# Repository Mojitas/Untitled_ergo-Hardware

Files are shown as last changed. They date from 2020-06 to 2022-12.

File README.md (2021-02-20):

# untitled_ergo-Hardware, I don't really know what to call this yet.
A split BLE keyboard with thoughts put into thumb key placement.
Looks like a Kyria keyboard except for uniform 5mm staggering and specifically made for being wireless. 
Draws a lot of inspiration from Mitosis.

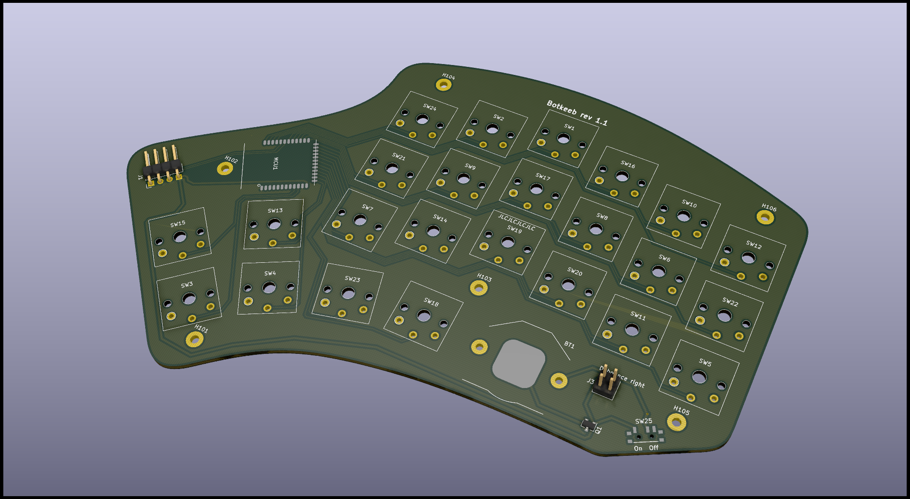
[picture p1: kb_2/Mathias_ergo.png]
Untitled ergo


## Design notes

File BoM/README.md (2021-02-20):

# Parts list
Parts required for a Botkeeb

## Keyboard

Line | Description | Quantity | Links
--- | --- | --- | ---
1 | BotKeeb Keyboard PCB | 2 | [files](https://github.com/mojitas/Untitled_ergo-Hardware/kb_2/gerbers), [ordering](http://jlcpcb.com)
2 | Core51822 (B) Module | 2 | [direct](http://www.waveshare.com/core51822-b.htm), [aliexpress](https://www.aliexpress.com/w/wholesale-core51822-b.html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)
3 | FDV301N (or any other pin-compatible low voltage nFET) | 2 | [digikey](https://www.digikey.se/product-detail/sv/on-semiconductor/FDV301N/FDV301NTR-ND/458851)
4 | Right angle 0.1" header (for optional programming header) | 2x 4pin | 
5 | CR2032 Battery | 2 | 
6 | Kailh choc compatible switches | 48 |
7 | Keycaps | 48x 1U | 

To be continued..

Straight of mitosis:

## Receiver
Line | Description | Quantity | Links
--- | --- | --- | ---
1 | Receiver Interface PCB | 1 | [files](https://github.com/reversebias/mitosis-hardware/tree/master/gerbers), [ordering](http://oshpark.com)
2 | Core51822 (B) Module | 1 | [direct](http://www.waveshare.com/core51822-b.htm), [aliexpress](https://www.aliexpress.com/w/wholesale-core51822-b.html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)
3 | Arduino Pro Mirco | 1 | 
4 | Cree CLVBA-FKA (or any other pin-compatible PLCC-4 LED) | 1 | [digikey](https://www.digikey.com/product-detail/en/cree-inc/CLVBA-FKA-CAEDH8BBB7A363/CLVBA-FKA-CAEDH8BBB7A363CT-ND/2650500)
5 | 1117 3.3v regulator in SOT223 (many types available) | 1 | [digikey](https://www.digikey.com/product-detail/en/diodes-incorporated/AZ1117IH-3.3TRG1/AZ1117IH-3.3TRG1DICT-ND/5699682)
6 | 1206 4.7k resistor array | 2 | [digikey](https://www.digikey.com/product-detail/en/stackpole-electronics-inc/RAVF164DJT4K70/RAVF164DJT4K70CT-ND/2425255)
7 | SMD tactile button (many compatible) | 2 | [digikey](https://www.digikey.com/product-detail/en/c-k/PTS525SM15SMTR2-LFS/CKN9104CT-ND/1146923)
8 | Right angle 0.1" header (for optional programming header) | 1x 4pin | 
9 | Straight 0.1" header (for stacking boards) | 2x 6pin |

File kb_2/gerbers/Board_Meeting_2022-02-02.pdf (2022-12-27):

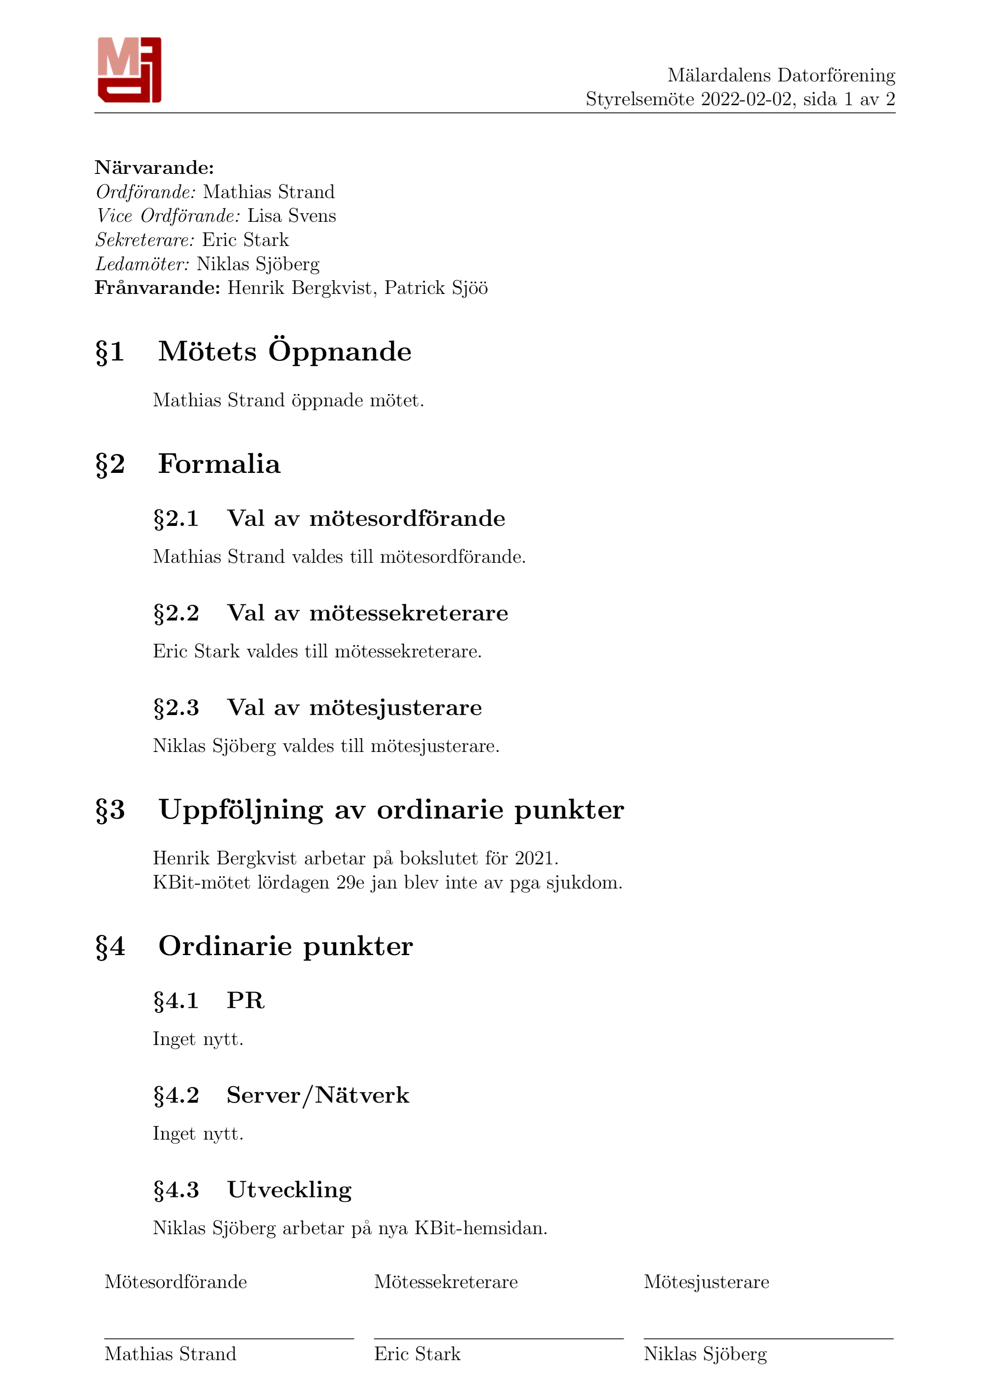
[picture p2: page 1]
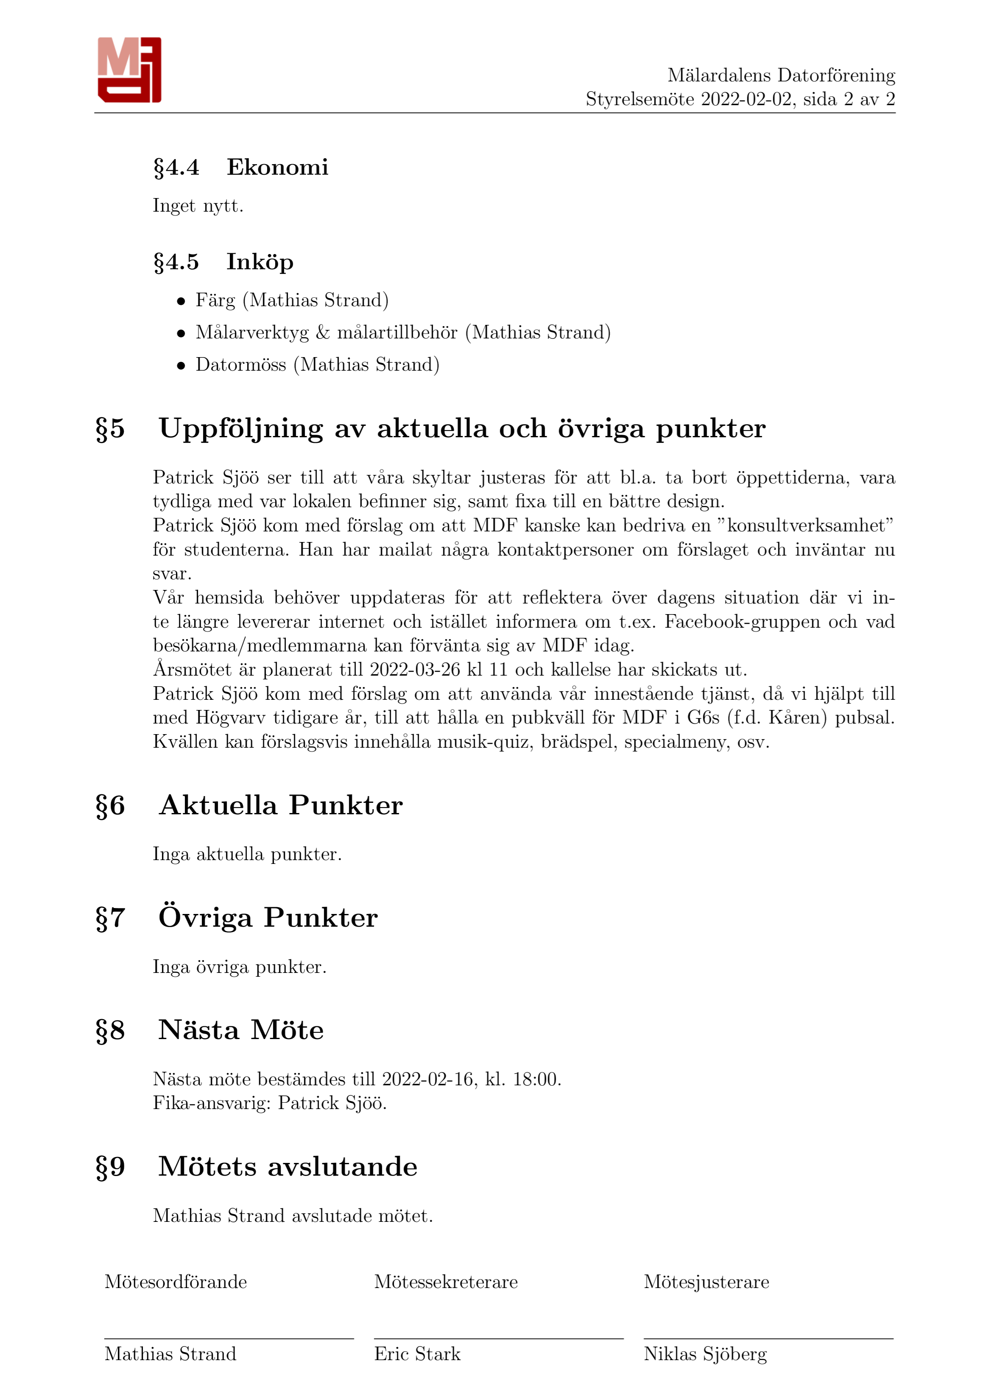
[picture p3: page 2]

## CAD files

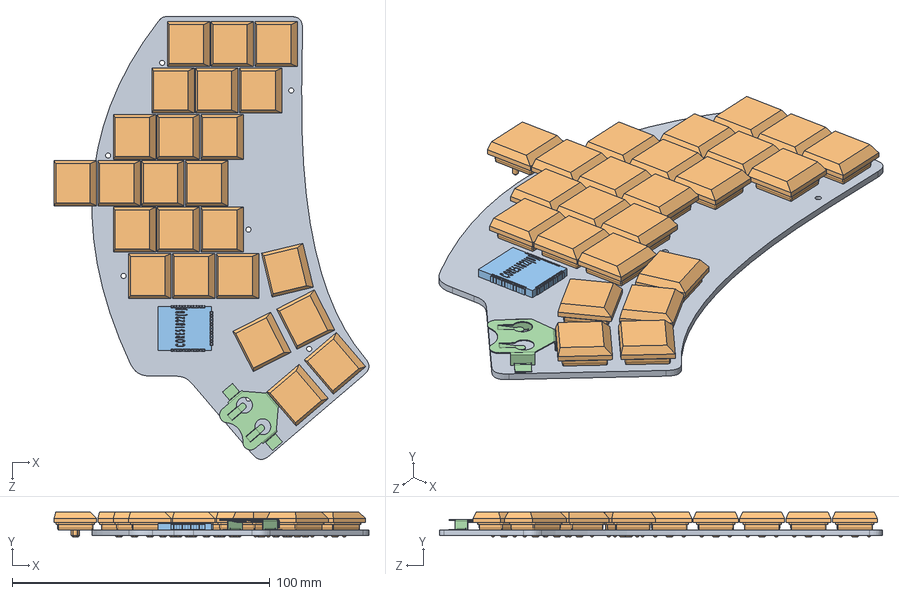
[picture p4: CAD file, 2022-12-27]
CAD_files/BottomPlate_S_24.SLDASM
122.3 x 9.65 x 172.0 mm
Switch_pcb_mount
Kailh_low_profile_switch x 23
Core51822(B)
batterihållare

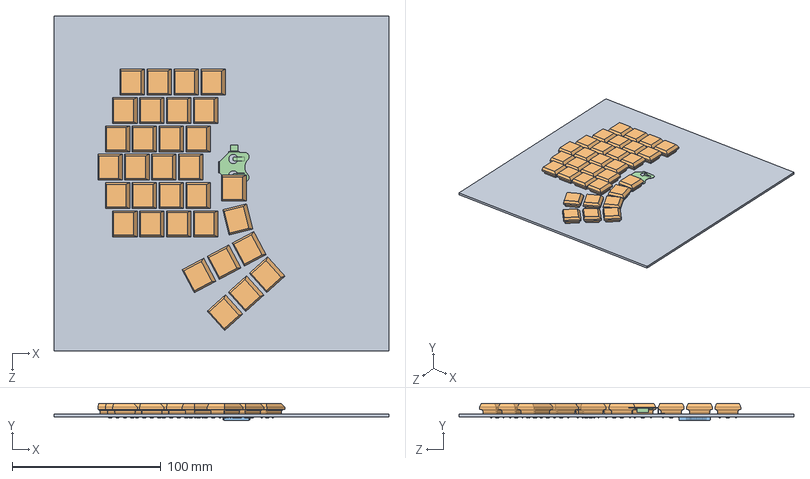
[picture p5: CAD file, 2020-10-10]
CAD_files/BP_28_antenna_concerns.SLDASM
225.0 x 11.5 x 225.0 mm
Switch_pcb_mount
Kailh_low_profile_switch x 32
Core51822(B)
batterihållare

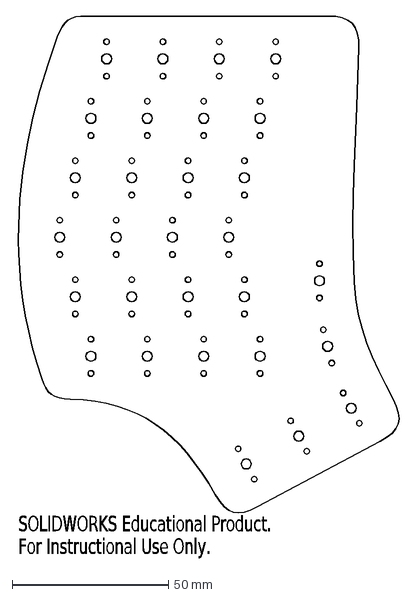
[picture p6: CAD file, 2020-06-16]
CAD_exports/Board_outline_rev1.DXF
SOLIDWORKS Educational Product.
For Instructional Use Only.

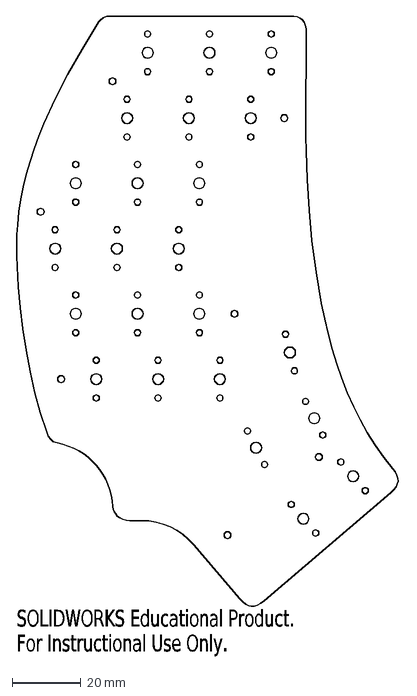
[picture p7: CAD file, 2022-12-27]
CAD_files/BottomPlate_export_30-12-2021.DXF
SOLIDWORKS Educational Product.
For Instructional Use Only.

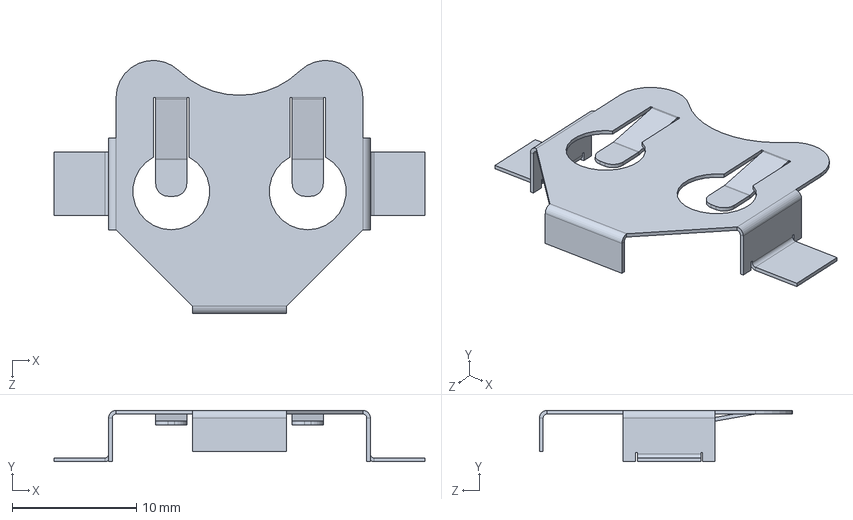
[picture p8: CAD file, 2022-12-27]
CAD_files/batterihållare.SLDPRT
29.9 x 4.12 x 20.4 mm

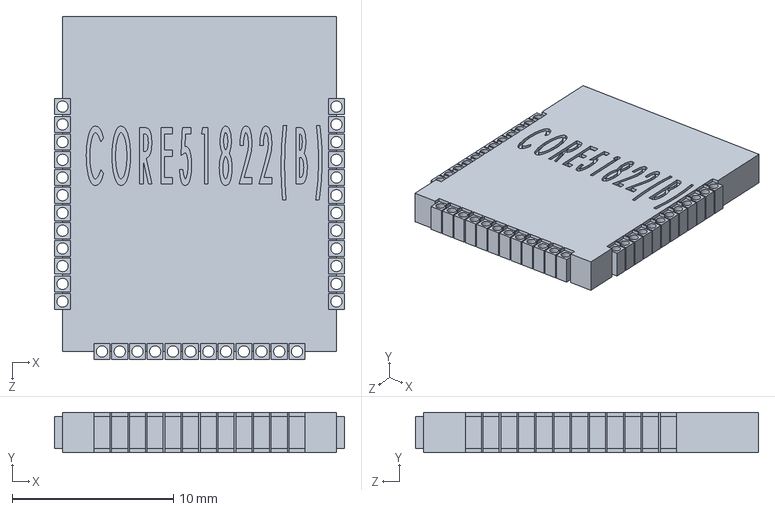
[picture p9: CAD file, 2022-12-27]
CAD_files/Core51822(B).SLDPRT
18.0 x 2.50 x 21.3 mm

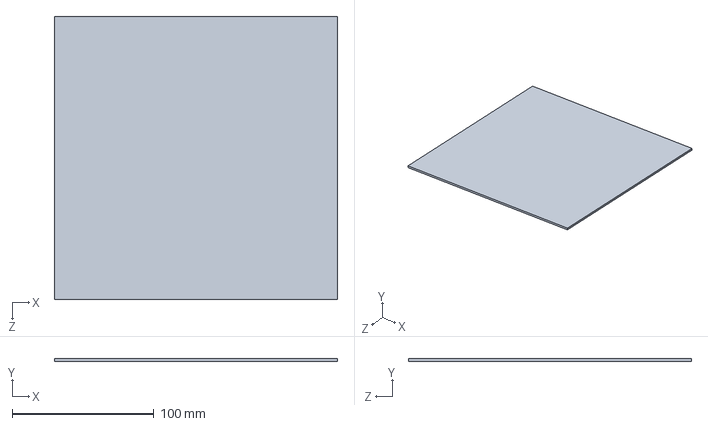
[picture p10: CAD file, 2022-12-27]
CAD_files/Switch_pcb_mount.SLDPRT
200.0 x 2.00 x 200.0 mm

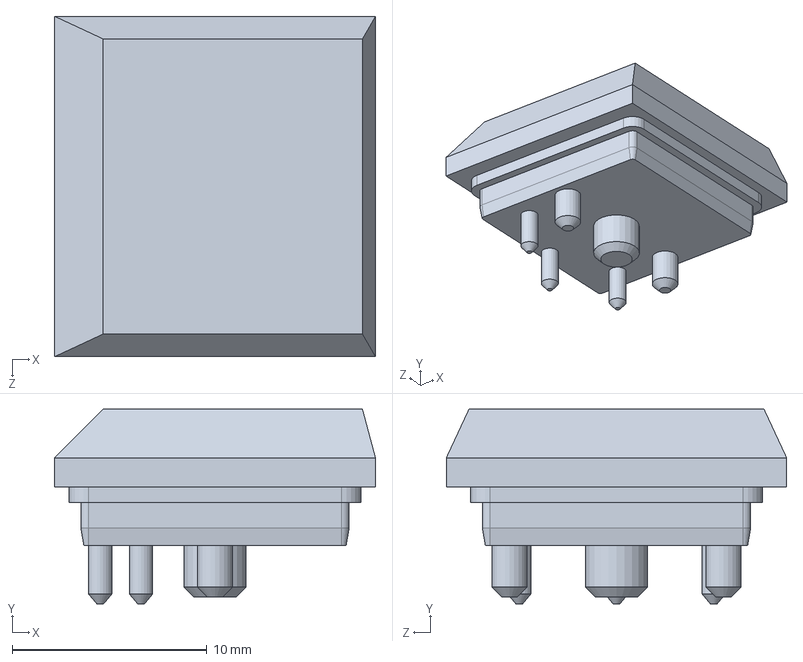
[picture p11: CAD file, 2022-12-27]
CAD_files/Kailh_low_profile_switch.SLDPRT
16.5 x 10.0 x 17.5 mm

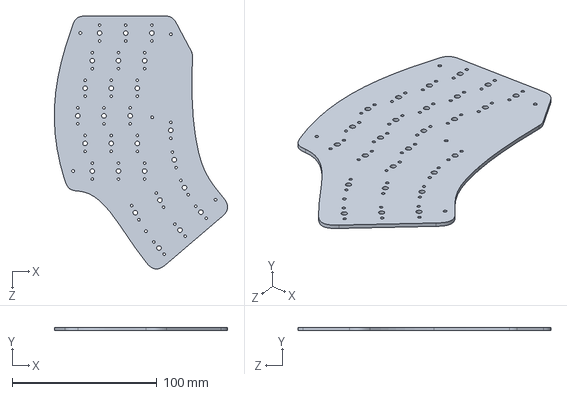
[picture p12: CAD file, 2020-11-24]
CAD_files/BottomPlate_24_switch_pcb_outline_24-11-2020.SLDPRT
119.6 x 2.00 x 174.6 mm

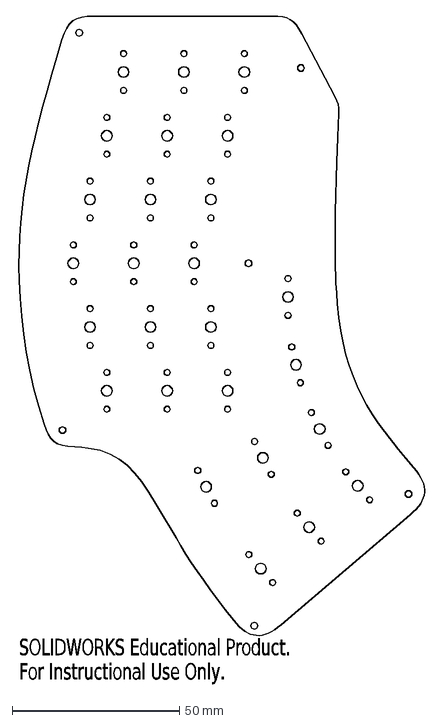
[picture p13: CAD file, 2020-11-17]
CAD_files/BottomPlate_export_17-11-2020.DXF
SOLIDWORKS Educational Product.
For Instructional Use Only.

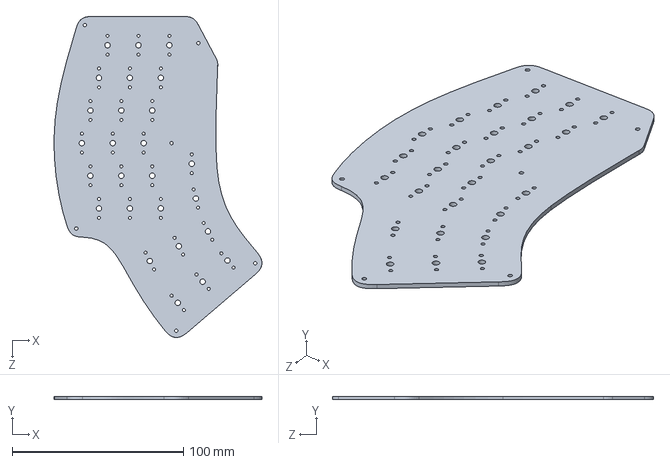
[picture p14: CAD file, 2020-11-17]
CAD_files/BottomPlate_24_switch_pcb_outline_13-11-2020.SLDPRT
121.3 x 2.00 x 187.3 mm

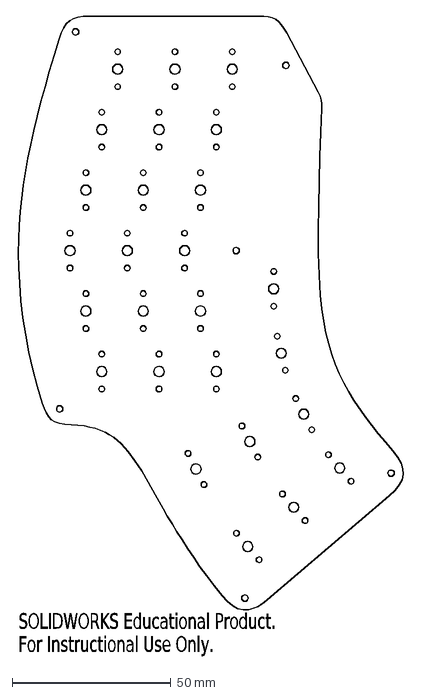
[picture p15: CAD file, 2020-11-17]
CAD_files/BottomPlate_export_13-11-2020.DXF
SOLIDWORKS Educational Product.
For Instructional Use Only.

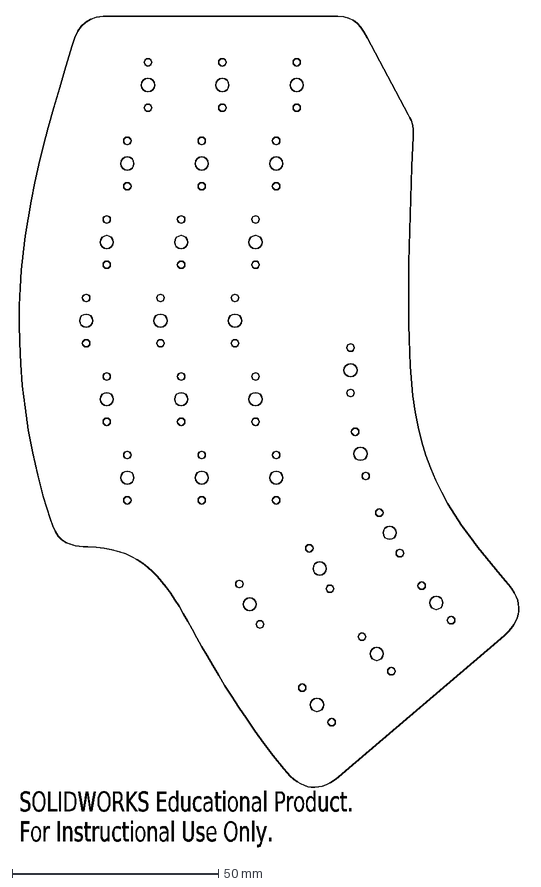
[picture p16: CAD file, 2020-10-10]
CAD_files/Board_outline_24.DXF
SOLIDWORKS Educational Product.
For Instructional Use Only.

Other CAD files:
CAD_files/BP_28_antenna_concerns.SLDPRT
CAD_files/BottomPlate_24_switch_pcb_outline_24-11-2020.DXF
CAD_files/BottomPlate_S_24.DXF
CAD_files/BottomPlate_S_24.SLDPRT

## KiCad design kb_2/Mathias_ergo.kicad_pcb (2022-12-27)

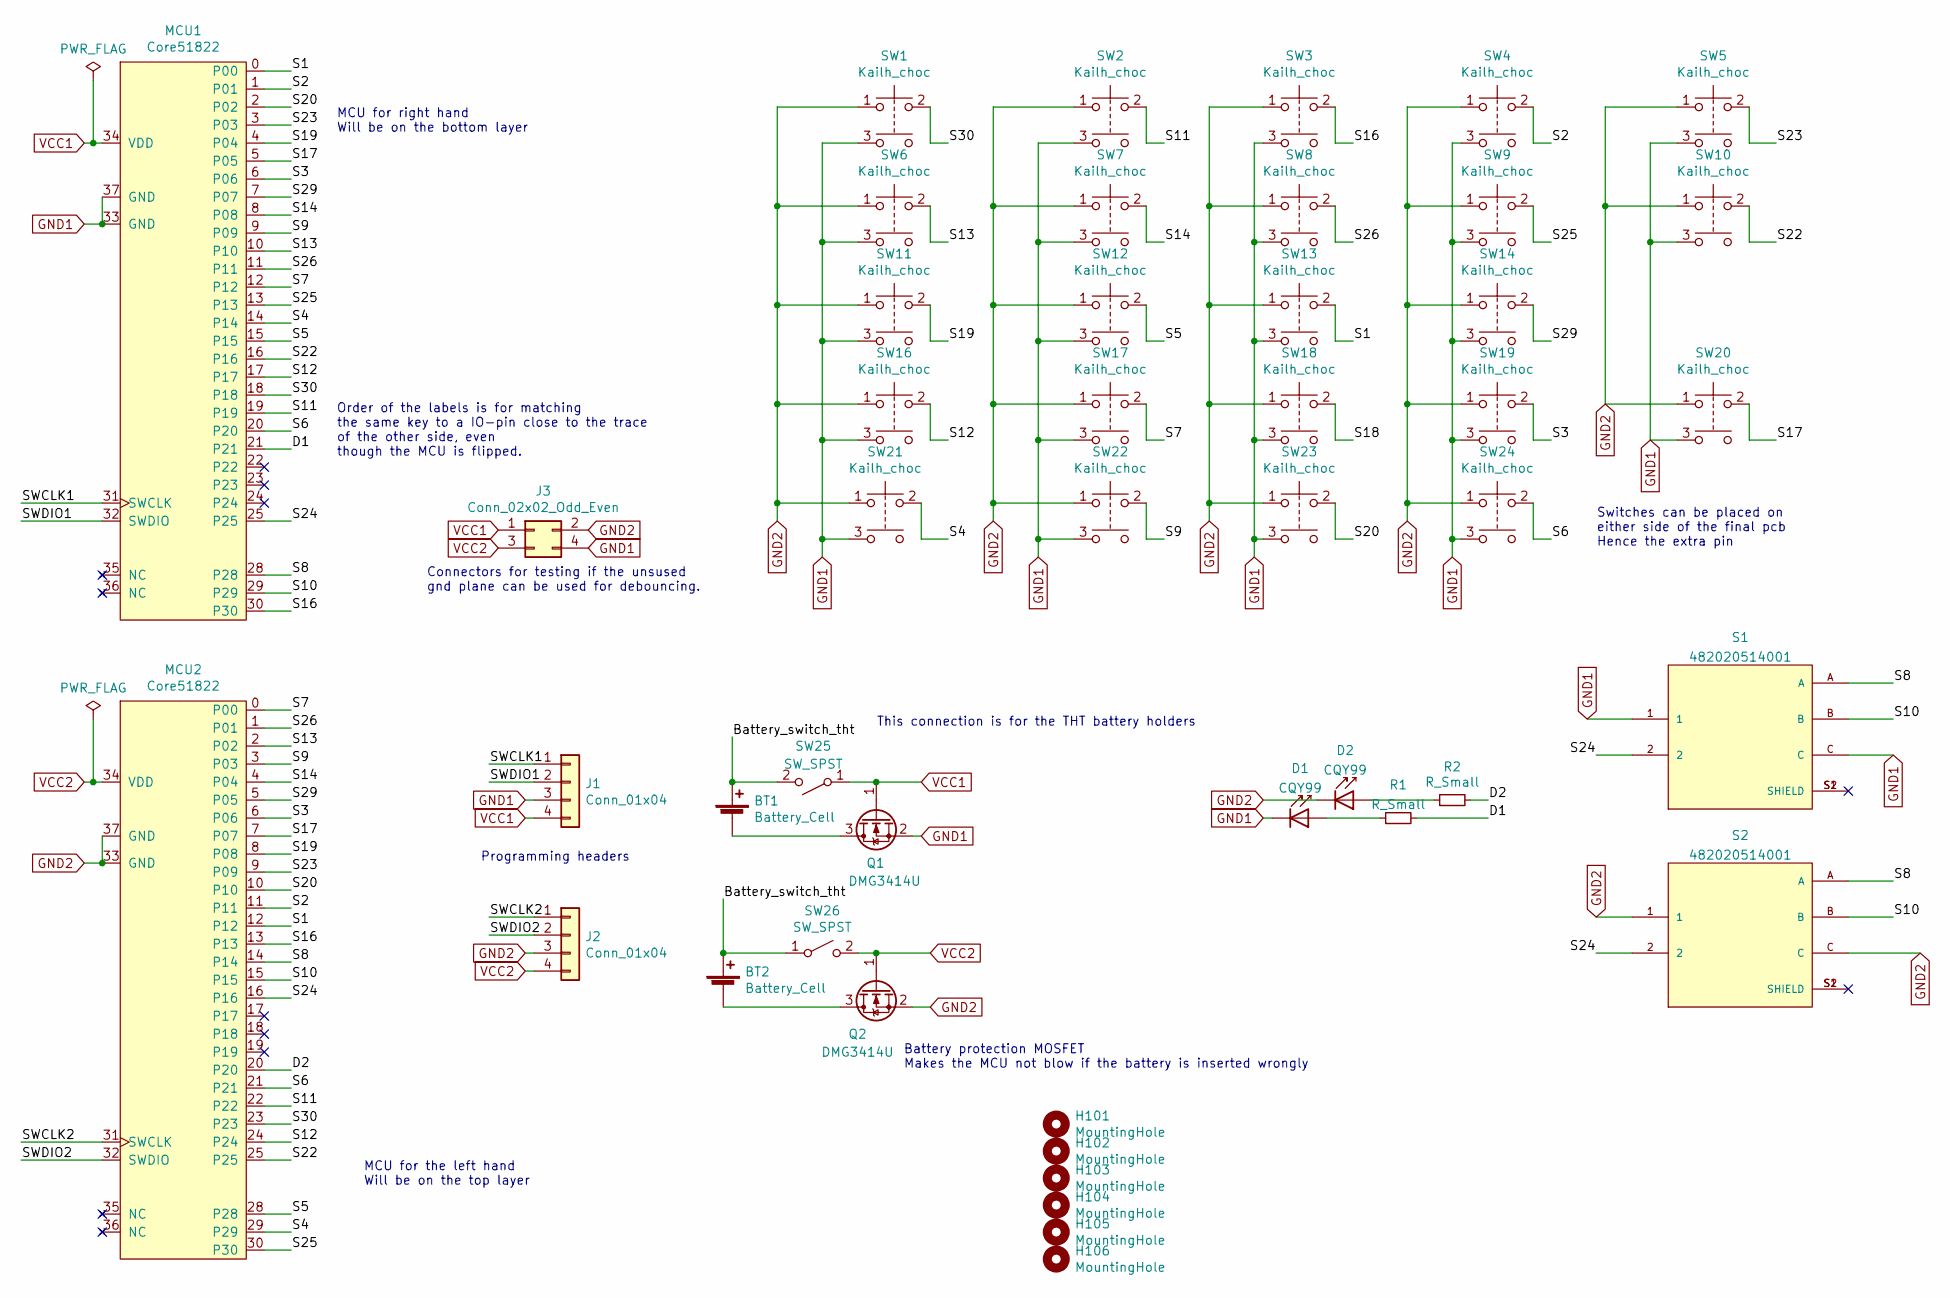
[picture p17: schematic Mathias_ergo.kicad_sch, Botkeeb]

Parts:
BT1, BT2: Battery_Cell; Battery_mod_tht
D1, D2: CQY99; D_0603_1608Metric
H101, H102, H103, H104, H105, H106: MountingHole; MountingHole_2.2mm_M2_Pad
J1, J2: Conn_01x04; PinHeader_1x04_P2.54mm_Horizontal
J3: Conn_02x02_Odd_Even; PinHeader_2x02_P2.54mm_Vertical
MCU1, MCU2: Core51822; YJ14015
Q1, Q2: DMG3414U; SOT-23
R1, R2: R_Small; R_0603_1608Metric
S1, S2: 482020514001; SW_482020514001; PARTREV 001.000
SW1, SW2, SW3, SW4, SW5, SW6, SW7, SW8, SW9, SW10, SW11, SW12, SW13, SW14, SW16, SW17, SW18, SW19, SW20, SW21, SW22, SW23, SW24: Kailh_choc; Kailh_low_profile
SW25, SW26: SW_SPST; PCM12SMTR

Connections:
/Battery_switch_tht: BT1.1 (+), BT2.1 (+), SW25.2 (B), SW26.1 (A)
/D1: MCU1.21, R1.2
/D2: MCU2.20, R2.2
/S1: MCU1.0, MCU2.12, SW13.2
/S2: MCU1.1, MCU2.11, SW4.2
/S3: MCU1.6, MCU2.6, SW19.2
/S4: MCU1.14, MCU2.29, SW21.2
/S5: MCU1.15, MCU2.28, SW12.2
/S6: MCU1.20, MCU2.21, SW24.2
/S7: MCU1.12, MCU2.0, SW17.2
/S8: MCU1.28, MCU2.14, S1.A, S2.A
/S9: MCU1.9, MCU2.3, SW22.2
/S10: MCU1.29, MCU2.15, S1.B, S2.B
/S11: MCU1.19, MCU2.22, SW2.2
/S12: MCU1.17, MCU2.24, SW16.2
/S13: MCU1.10, MCU2.2, SW6.2
/S14: MCU1.8, MCU2.4, SW7.2
/S16: MCU1.30, MCU2.13, SW3.2
/S17: MCU1.5, MCU2.7, SW20.2
/S19: MCU1.4, MCU2.8, SW11.2
/S20: MCU1.2, MCU2.10, SW23.2
/S22: MCU1.16, MCU2.25, SW10.2
/S23: MCU1.3, MCU2.9, SW5.2
/S24: MCU1.25, MCU2.16, S1.2, S2.2
/S25: MCU1.13, MCU2.30, SW9.2
/S26: MCU1.11, MCU2.1, SW8.2
/S29: MCU1.7, MCU2.5, SW14.2
/S30: MCU1.18, MCU2.23, SW1.2
/SWCLK1: J1.1, MCU1.31 (SWCLK)
/SWCLK2: J2.1, MCU2.31 (SWCLK)
/SWDIO1: J1.2, MCU1.32 (SWDIO)
/SWDIO2: J2.2, MCU2.32 (SWDIO)
GND1: D1.1 (K), J1.3, J3.4, MCU1.33 (GND), MCU1.37 (GND), Q1.2 (S), S1.1, S1.C, SW1.3, SW2.3, SW3.3, SW4.3, SW5.3, SW6.3, SW7.3, SW8.3, SW9.3, SW10.3, SW11.3, SW12.3, SW13.3, SW14.3, SW16.3, SW17.3, SW18.3, SW19.3, SW20.3, SW21.3, SW22.3, SW23.3, SW24.3
GND2: D2.1 (K), J2.3, J3.2, MCU2.33 (GND), MCU2.37 (GND), Q2.2 (S), S2.1, S2.C, SW1.1, SW2.1, SW3.1, SW4.1, SW5.1, SW6.1, SW7.1, SW8.1, SW9.1, SW10.1, SW11.1, SW12.1, SW13.1, SW14.1, SW16.1, SW17.1, SW18.1, SW19.1, SW20.1, SW21.1, SW22.1, SW23.1, SW24.1
unnamed: BT1.2 (-), Q1.3 (D)
unnamed: BT2.2 (-), Q2.3 (D)
unnamed: D1.2 (A), R1.1
unnamed: D2.2 (A), R2.1
VCC1: J1.4, J3.1, MCU1.34 (VDD), Q1.1 (G), SW25.1 (A)
VCC2: J2.4, J3.3, MCU2.34 (VDD), Q2.1 (G), SW26.2 (B)

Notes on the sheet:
MCU for the left hand Will be on the top layer
MCU for right hand Will be on the bottom layer
This connection is for the THT battery holders
Connectors for testing if the unsused gnd plane can be used for debouncing.
Switches can be placed on either side of the final pcb Hence the extra pin
Order of the labels is for matching the same key to a IO-pin close to the trace of the other side, even though the MCU is flipped.
Battery protection MOSFET Makes the MCU not blow if the battery is inserted wrongly
Programming headers

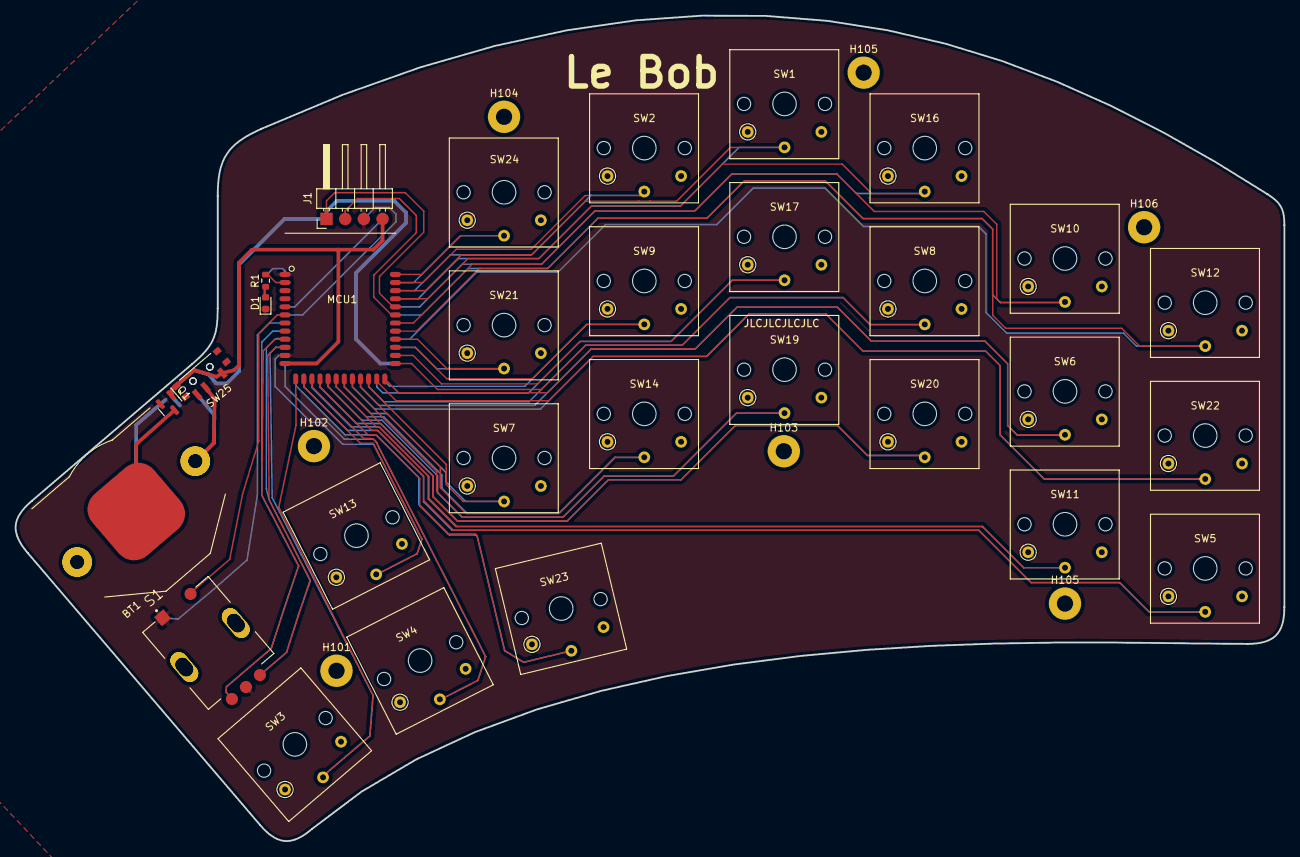
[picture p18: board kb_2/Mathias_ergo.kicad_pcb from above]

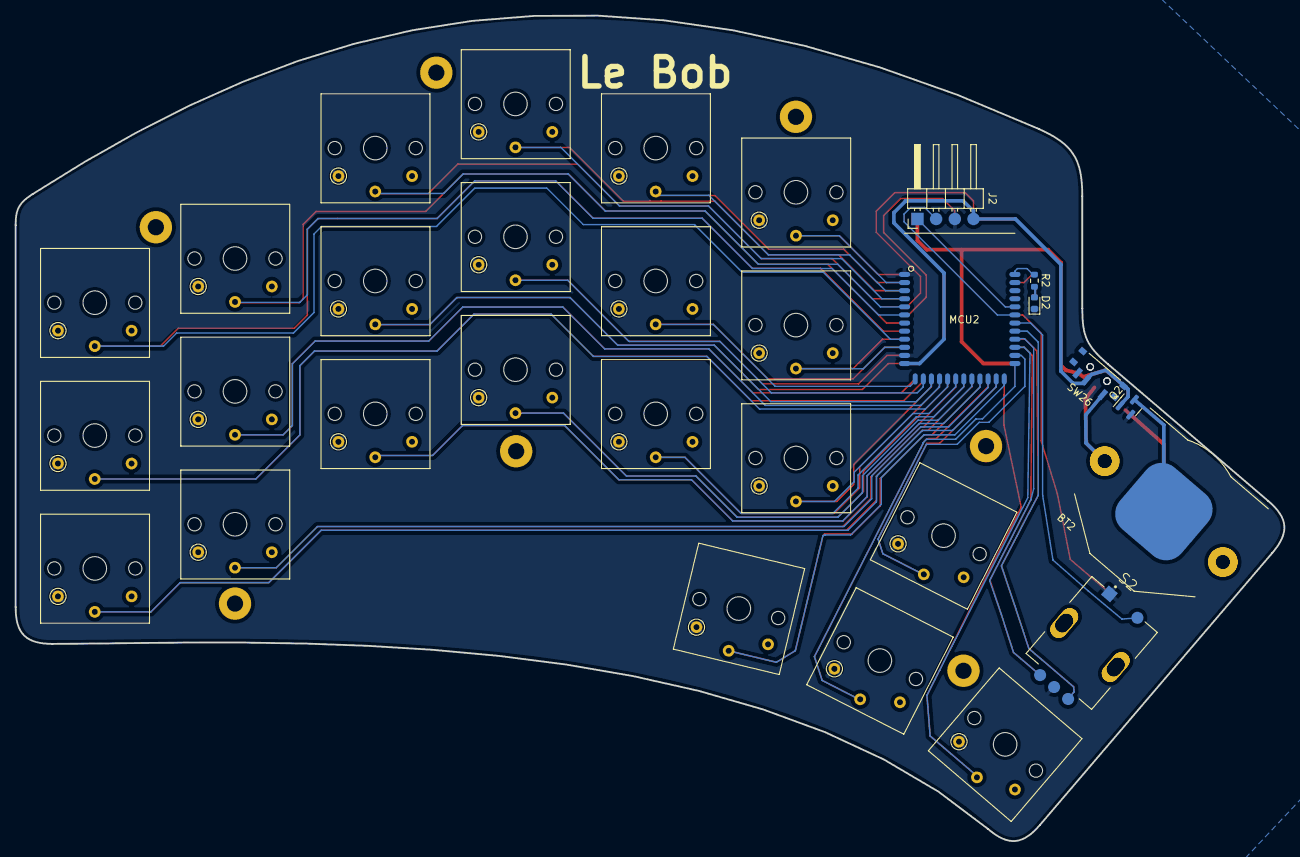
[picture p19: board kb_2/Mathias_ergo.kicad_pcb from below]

Board: 2 copper layers, 172.3 x 112.1 mm, 45 parts (8 on the bottom side), 40 nets.

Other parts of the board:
H105#2: MountingHole; MountingHole_2.2mm_M2_Pad

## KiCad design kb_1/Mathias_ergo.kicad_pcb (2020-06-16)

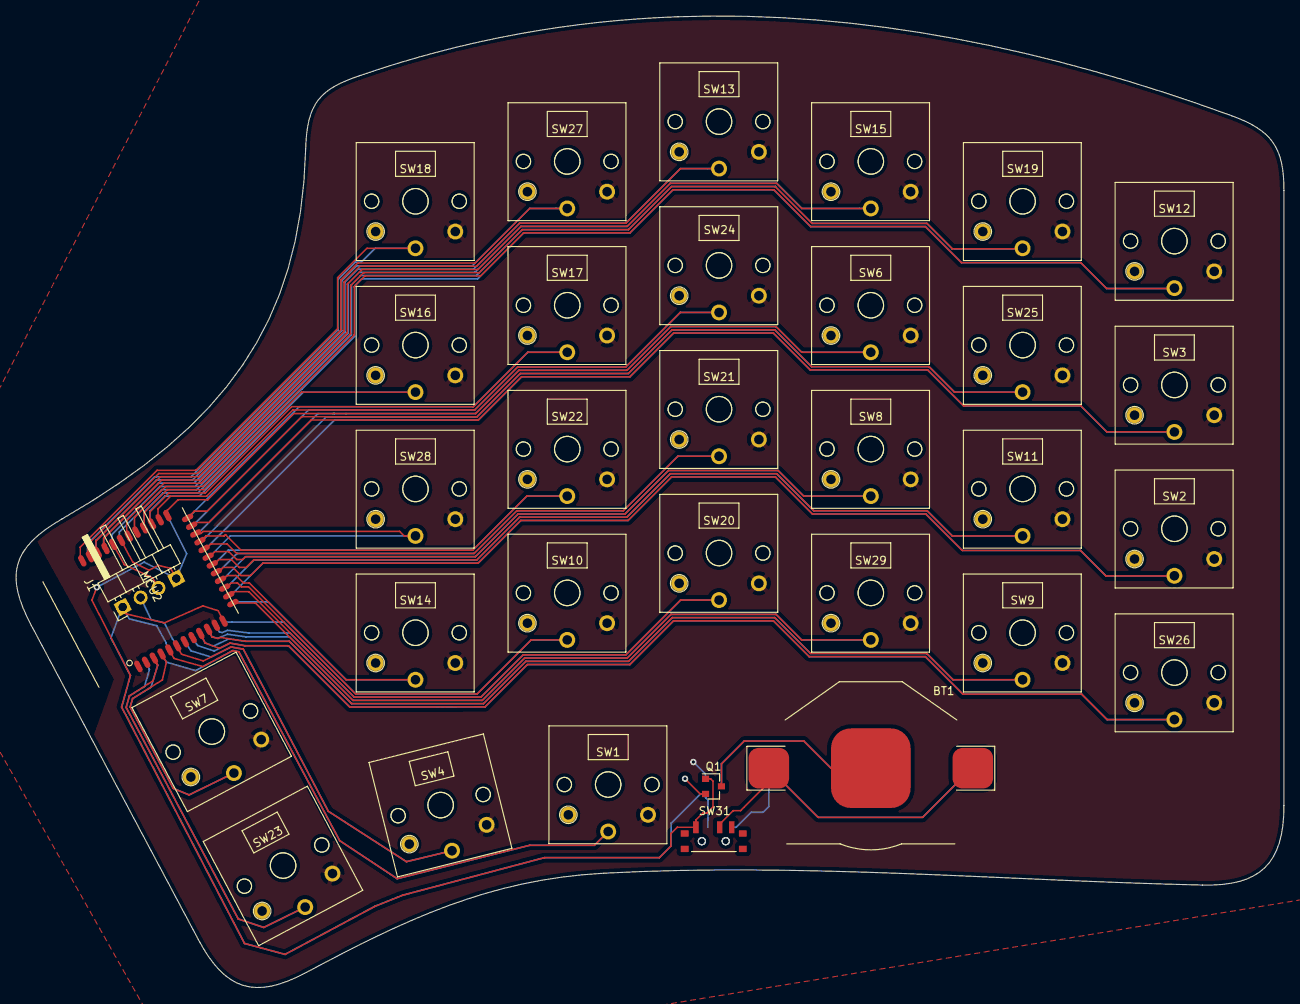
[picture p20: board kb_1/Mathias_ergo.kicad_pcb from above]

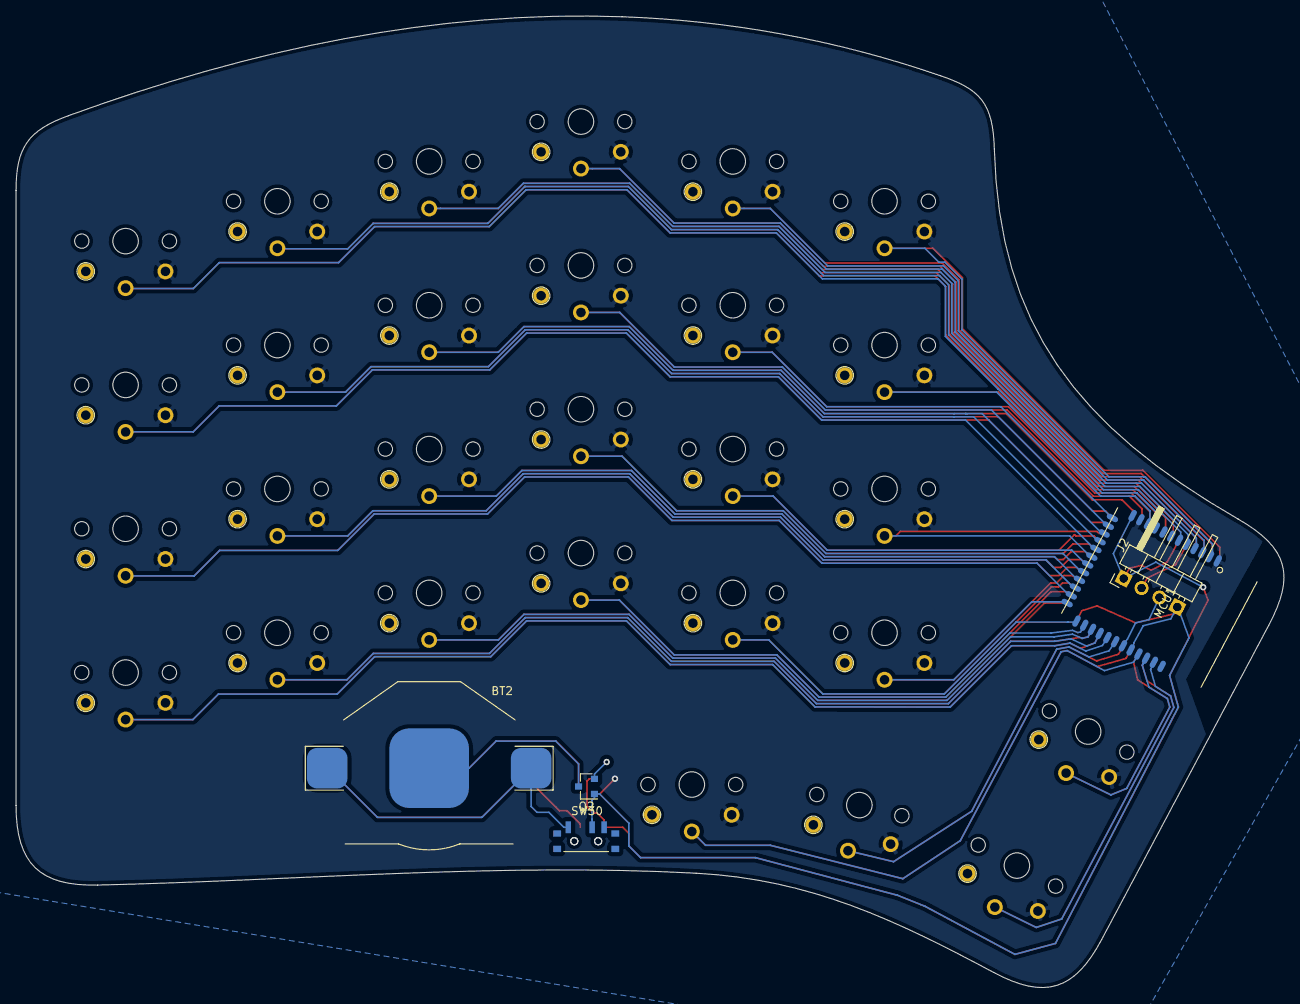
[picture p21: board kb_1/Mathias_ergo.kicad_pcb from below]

Board: 2 copper layers, 159.1 x 121.9 mm, 38 parts (5 on the bottom side), 40 nets.

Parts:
BT1, BT2: Battery_Cell; Battery_mod
J1, J2: Conn_01x04; PinHeader_1x04_P2.54mm_Horizontal
MCU1, MCU2: Core51822; YJ14015
Q1, Q2: DMG3414U; SOT-23
SW1, SW2, SW3, SW4, SW6, SW7, SW8, SW9, SW10, SW11, SW12, SW13, SW14, SW15, SW16, SW17, SW18, SW19, SW20, SW21, SW22, SW23, SW24, SW25, SW26, SW27, SW28, SW29: SW_Push_Dual; Kailh_low_profile
SW30, SW31: SW_SPST; PCM12SMTR

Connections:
/S1: MCU1.24, MCU2.17, SW15.2
/S2: MCU1.25, MCU2.16, SW19.2
/S3: MCU1.5, MCU2.7, SW22.2
/S4: MCU1.13, MCU2.30, SW29.2
/S5: MCU1.14, MCU2.29, SW9.2
/S6: MCU1.19, MCU2.22, SW23.2
/S7: MCU1.11, MCU2.1, SW10.2
/S8: MCU1.0, MCU2.12, SW24.2
/S9: MCU1.8, MCU2.4, SW11.2
/S11: MCU1.18, MCU2.23, SW7.2
/S12: MCU1.16, MCU2.25, SW4.2
/S13: MCU1.9, MCU2.3, SW2.2
/S14: MCU1.7, MCU2.5, SW8.2
/S15: MCU1.1, MCU2.11, SW6.2
/S16: MCU1.23, MCU2.18, SW13.2
/S17: MCU1.4, MCU2.8, SW28.2
/S18: MCU1.29, MCU2.14, SW16.2
/S19: MCU1.3, MCU2.9, SW3.2
/S20: MCU1.30, MCU2.13, SW17.2
/S21: MCU1.21, MCU2.20, SW18.2
/S22: MCU1.15, MCU2.28, SW26.2
/S23: MCU1.2, MCU2.10, SW25.2
/S24: MCU1.22, MCU2.19, SW27.2
/S25: MCU1.12, MCU2.0, SW20.2
/S26: MCU1.10, MCU2.2, SW14.2
/S28: MCU1.28, MCU2.15, SW12.2
/S29: MCU1.6, MCU2.6, SW21.2
/S30: MCU1.17, MCU2.24, SW1.2
/SWCLK1: J1.1, MCU1.31
/SWCLK2: J2.2, MCU2.31
/SWDIO1: J1.2, MCU1.32
/SWDIO2: J2.1, MCU2.32
GND1: J1.3, MCU1.33, MCU1.37, Q1.2, SW1.3, SW2.3, SW3.3, SW4.3, SW6.3, SW7.3, SW8.3, SW9.3, SW10.3, SW11.3, SW12.3, SW13.3, SW14.3, SW15.3, SW16.3, SW17.3, SW18.3, SW19.3, SW20.3, SW21.3, SW22.3, SW23.3, SW24.3, SW25.3, SW26.3, SW27.3, SW28.3, SW29.3
GND2: J2.3, MCU2.33, MCU2.37, Q2.2, SW1.1, SW2.1, SW3.1, SW4.1, SW6.1, SW7.1, SW8.1, SW9.1, SW10.1, SW11.1, SW12.1, SW13.1, SW14.1, SW15.1, SW16.1, SW17.1, SW18.1, SW19.1, SW20.1, SW21.1, SW22.1, SW23.1, SW24.1, SW25.1, SW26.1, SW27.1, SW28.1, SW29.1
unnamed: BT1.1, SW31.2
unnamed: BT1.2, Q1.3
unnamed: BT2.1, SW30.1
unnamed: BT2.2, Q2.3
VCC1: J1.4, MCU1.34, Q1.1, SW31.1
VCC2: J2.4, MCU2.34, Q2.1, SW30.2

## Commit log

2020-03-27 Cad files added
    [bp_print.STL, button_placement.SLDASM, button_placement.SLDPRT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]
2020-03-27 Changed to more logical names
    [button_placement.SLDPRT, button_placement_asm.SLDASM, button_placement_prt.SLDPRT]
2020-03-27 Changed names
    [bottom_plate.SLDPRT, button.SLDPRT]
2020-06-09 Kicad folder with schematic and board layout added
    [Mathias_ergo.kicad_pcb, Mathias_ergo.sch]
2020-06-16 Changed and updated the pcb
    Libraries and footprints added
    [Mathias_ergo.kicad_pcb, Mathias_ergo.sch]
2020-06-16 Changed names
    Updated names and added board outline
    [Board_outline.DXF, Kailh_low prof_switch.SLDPRT, Switch_placement_asm.SLDASM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]
2020-06-16 Replaced old files
    [BP_28_antenna_concerns.SLDASM, BP_28_antenna_concerns.SLDPRT, Board_outline_rev1.DXF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]
2020-06-16 replaced test print file
    [Switch_placement_print.STL]
2020-10-10 Newer design that I like more
    [BP_28_antenna_concerns.SLDASM, Board_outline_24.DXF, BottomPlate_S_24.SLDASM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]
2020-11-13 added silkscreen
    [Mathias_ergo.kicad_pcb, Mathias_ergo.sch]
2020-11-13 some author things
    [Mathias_ergo.kicad_pcb, Mathias_ergo.sch]
2020-11-17 Design rules check
    [Mathias_ergo.kicad_pcb]
2020-11-17 Added defined positions for mounting holes
    [BottomPlate_24_switch_pcb_outline_13-11-2020.SLDPRT, BottomPlate_S_24.SLDASM, BottomPlate_export_13-11-2020.DXF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]
2020-11-17 Some fixes on outline
    [BottomPlate_S_24.SLDASM, BottomPlate_S_24.SLDPRT, BottomPlate_export_17-11-2020.DXF]
2020-11-24 New outline
    Fixed the board outline,
    thumb buttons positions,
    battery footprint,
    gnd pours
    [BottomPlate_24_switch_pcb_outline_24-11-2020.DXF, BottomPlate_24_switch_pcb_outline_24-11-2020.SLDPRT, BottomPlate_S_24.SLDASM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]
2021-01-29 Send to factory version
    [Mathias_ergo.kicad_pcb, Mathias_ergo.sch]
2021-01-31 Exported gerbers
    [Mathias_ergo-B_Cu.gbl, Mathias_ergo-B_Mask.gbr, Mathias_ergo-B_Mask.gbs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]
2021-02-20 Added BoM for 1 either half
2021-02-20 Added BoM
2021-02-20 Added more clearances between traces
    [Mathias_ergo.kicad_pcb]
2021-05-26 added last
    [Mathias_ergo.kicad_pcb]
2022-12-27 pushing before wipe
    [BottomPlate_S_24.SLDASM, BottomPlate_S_24.SLDPRT, Core51822(B).SLDPRT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]
2022-12-27 Adding before wipe
    [BottomPlate_S_24.DXF, BottomPlate_export_30-12-2021.DXF, Mathias_ergo.kicad_sch]
